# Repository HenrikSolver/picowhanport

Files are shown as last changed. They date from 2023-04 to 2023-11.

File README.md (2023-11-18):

# Ett enkelt sätt att koppla din nya elmätare till en MQTT broker

## Hårdvara
Koppla ihop en 6 pinnars RJ-12 kontakt med picon enligt följande.

| RJ-12 |RJ- 12| RPI |
|---|---|-----|
| 1 (Vcc) | 2 (dataReq) | 39 (VSYS) |
| 5 (data out) | | 7 (UART1 Rx)
| 6 (GND) | | 38 (GND)|

Sätt ett pull upp motstånd på omkring 3 Kohm mellan 7 (UART1 Rx) 36 (3,3V) på pico. Allt enligt nedanstående schema (bidrag från @speedbird620)
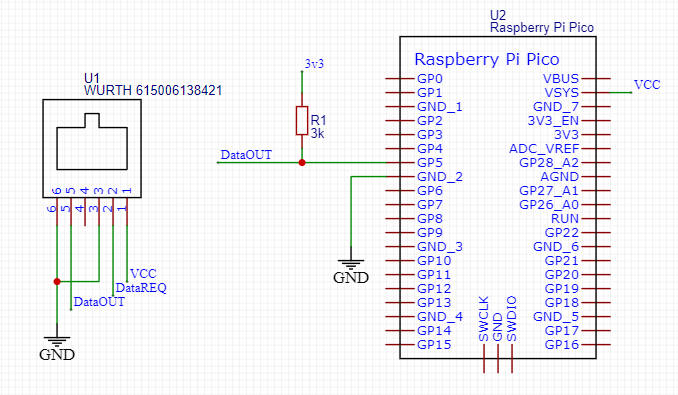
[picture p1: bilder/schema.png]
bild2


## Mjukvara
Installera micropython och mpremote
* https://micropython.org/download/rp2-pico-w/
* https://docs.micropython.org/en/latest/reference/mpremote.html

Modifiera `config.py`så innehållet passar ditt nätverk.
kopiera `config.py` till picon med `mpremote.py cp config.py :config.py`

Installera paketet umqtt.simple med följande 
```python
import mip
import network
import config

wlan = network.WLAN(network.STA_IF)
wlan.active(True)
wlan.connect(config.SSID, config.PSK)

mip.install("umqtt.simple")
```

kopiera `boot.py` och `main.py` till picon med mpremote

koppla in picon till din elmätares HAN port med en rak (altså pin 1 går till pin 1 o.s.v) RJ-12 kabel. LED'en blinkar med omkring 2 Hz medan picon försöker koppla sig till WLAN. När den är uppkopplad lyser den med fast sken men släcks en kort stund för varje gång den får data från elmätaren som skickas till MQTT brokern. Denna släckning skall ske var tionde sekund. Hade det varit en fyr så hade den haft karaktären `Oc 10s`

### komponentlista
Detta är de delar jag använt i bygget, man kan naturligtvis köpa motsvarande någon annanstans. Du behöver också en tång för att klämma modularkontakterna.

* https://www.electrokit.com/produkt/modularkontakt-6-6/
* https://www.electrokit.com/produkt/modularkontakt-6-6-pcb/
* https://www.electrokit.com/produkt/adapterkort-for-rj11-kontakt-2-pack/
* https://www.electrokit.com/produkt/telekabel-6x-0-08mm%c2%b2-platt-vit-m/
* https://www.electrokit.com/produkt/raspberry-pi-pico-w/
* https://www.electrokit.com/produkt/metallfilmsmotstand-0-25w-3-01kohm-1-3k01/

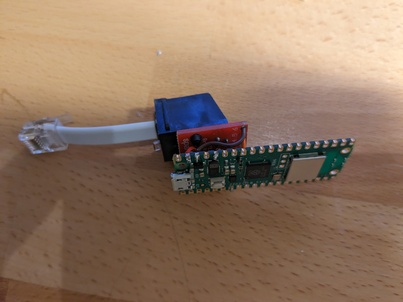
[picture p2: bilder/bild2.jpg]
bild2


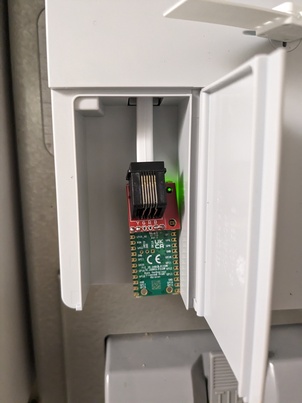
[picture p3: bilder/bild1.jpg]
bild1


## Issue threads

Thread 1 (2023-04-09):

Potential further development: Split Topic into JSON

lillknurra, 2023-04-09:
Hi,
I'm able to get the data into Home Assistant, but it's not easy to make use of the data.

Would it be possible to parse the data into several topics in JSON format?
From this:
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
To something like this:
{ "MeterID":"LGF5E360","1.0.0":"230408233550","1.8.0":"00029737.127","CRC16","0191" }

Or even splitting it further into separate topics...

Thanks,
Petter

JL-EU, 2023-06-04:
Hi,
I'm also trying to get this going, haven't managed to read data from the meter yet.
Did you manage to format the data?
Thanks,
Jacob

lillknurra, 2023-06-04:
Hi,
Yes I managed by reading the lines that are of interest-
I'm using it in home Assistant and created sensors in mqtt.yaml looking like this:
sensor:
  - name: "P1 Energy bought"
    unit_of_measurement: "kWh"
    state_topic: "hanmeter/data"
    device_class: energy
    state_class: total_increasing
    value_template: >-
      {{ value.split("\r\n")[3] | regex_findall_index("\((.+)[*]") | float }}
    icon: mdi:lightning-bolt
    force_update: true
  - name: "P1 Energy sold"
    unit_of_measurement: "kWh"
    state_topic: "hanmeter/data"
    device_class: energy
    state_class: total_increasing
    value_template: >-
      {{ value.split("\r\n")[4] | regex_findall_index("\((.+)[*]") | float }}
    icon: mdi:lightning-bolt
    force_update: true
  - name: "P1 Current Power In"
    unit_of_measurement: "kWh"
    state_topic: "hanmeter/data"
    value_template: >-
      {{ value.split("\r\n")[7] | regex_findall_index("\((.+)[*]") | float }}
    icon: mdi:flash
    force_update: true
  - name: "P1 Current Power Out"
    unit_of_measurement: "kWh"
    state_topic: "hanmeter/data"
    value_template: >-
      {{value.split("\r\n")[8] | regex_findall_index("\((.+)[*]") | float }}
    icon: mdi:flash
    force_update: true

HenrikSolver, 2023-11-09:
I was thinking of this, but then the CRC should be verified before converting the package to JSON, and I thought it was simpler to send the package to "the other side" where verifying the checksum is done by a Go program that stores the data in a influx db.

vilhelmericson, 2023-12-31:
Henrik's nice repository gave me good help to read out the values from my electricity meter's HAN port ([Kamstrup Omnipower](https://www.kamstrup.com/se-se/ellosningar/smarta-elmatare/meters/omnipower-three-phase-meter) + [Kamstrup HAN-P1](https://www.kamstrup.com/se-se/ellosningar/smarta-elmatare/modules/han-p1)) for Home Assistant using a Raspberry Pi Pico and MQTT. To do that, I needed to implement support for the steps that weren't part of Henrik's use case; verify the telegram based on the CRC checksum, interpret the telegram and pack it as a JSON object and then publish it in the MQTT server. The implementation is in the attached zip file, values for all settings are set in config.py. Attached is also an example of how the JSON objects look.
[picowhanport_ha.zip](https://github.com/HenrikSolver/picowhanport/files/13802371/picowhanport_ha.zip)
[telegram.json](https://github.com/HenrikSolver/picowhanport/files/13802372/telegram.json)

HenrikSolver, 2024-01-01:
Nice, and first thing on the new year :+1: . I will take a look and add it in one way or another.

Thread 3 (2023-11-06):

5v från HAN-port, 3v på Pico?!

speedbird620, 2023-11-06:
Hej @HenrikSolver,

Jag tolkar din skiss som att Data UT (PIN5 på RJ12) går till PIN7 på Pico:n.

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

Då processorn på PI Pico arbetar med 3 volt och HAN-portens utgång är på 5 volt, är detta inte enligt spec. Jag är rädd för att det finns risk finns att Picon pajar i längden.

En annan sak jag funderar på, när jag läser på forum så ska Data UT inverteras för att microprocessorn ska läsa informationen. I din design finns inte det inkluderat. Är detta något du löser i mjukvaran?

/mik

HenrikSolver, 2023-11-09:
Hej mik.
Tack för din fråga.
DataOut från  elmätaren är open collector och matas från 3,3v via 3k motståndet som nämns i instruktionerna, så det borde funka. Inventeringen löses i mjukvaran. Eller egentligen  genom att konfigurera UARTen så den inverterar signalen.
/Henrik

speedbird620, 2023-11-11:
Rgr. Då är jag med. Tack för svar.

Stämmer denna skiss?
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

HenrikSolver, 2023-11-11:
Ser bra ut. Vill du göra en PR på README filen för att lägga till skissen? Om du tycker det krångligt kan jag göra det själv (med en hänvisning till dig förstås) det tar mig inte så många minuter.

speedbird620, 2023-11-11:
Nu är jag inte direkt en fena på GitHub, så jag har ingen aning om hur man gör en PR. Om du vill så får du gärna återanvända skissen jag gjorde. Du behöver inte lämna någon referens.

gurka, 2024-11-14:
Hej,

Tänkte att jag kunde ställa lite frågor relaterat till skissen här istället för att göra en ny issue.

- Visst har det försvunnit i nya skissen att DataREQ ska kopplas mot VCC på RJ12:an?
- På tal om DataREQ: är det OK att koppla ihop denna med VCC direkt eller bör det sitta en resistor mellan? Aidon har skrivit så här i deras manual: `Ingång för databegäran är avsedd att sänka strömmen med 4,0–10,0 mA när den aktiveras`, men jag är inte säker på vad det innebär. Menar dom att det sitter en resistor eller motsvarande innanför HAN-porten?
- Spelar det någon roll att man bara kopplar GND från RJ12 till en GND-pinne på pico:n, som i andra skissen, eller bör man koppla den mot alla GND-pinnar som i första skissen?

HenrikSolver, 2024-11-14:
Halloj Gurka.

1. Det står i och för sig i tabellen att de skall kopplas ihopa, men jag håller med om att det kanske inte är supertydligt.
2. Den mest detaljerade informationen jag kan hitta på interfacet är [denna](https://www.netbeheernederland.nl/sites/default/files/2024-02/dsmr_5.0.2_p1_companion_standard.pdf). I schemat på sidan 7 sitter det ett motstånd mellan optokopplaren och data_request. Det verkar vettigt att det gör det för att skydda mätaren.
3. Det verkar inte spela någon roll, jag har bara kopplat in GND till en pinne, och det har fungerat fint.

Henrik

gurka, 2024-11-14:
Aha, så DataREQ och dess optokopplare blir då, mer eller mindre, som som en enkel LED seriekopplad med en resistor. 4mA-10mA är den ström som krävs för att driva denna optokopplare / LED.

Ska bli spännande att se om jag kan få till en fungerande läsare. Just nu verkar dock Pico W vara slutsåld hos de flesta återförsäljare, så vi får se när det blir.

Tack för svar!

gurka, 2024-11-19:
Jag har nog inte helt förstått hur optokopplaren och open collector fungerar.

Det sitter en LED och en transistor i optokopplaren. När LED:en lyser så blir DATA och DATA_GND sammankopplade via transistorn och man kan läsa ut 0V (low) på DATA? När LED:en inte lyser så bryts kopplingen mellan DATA och DATA_GND, och man kan istället läsa ut 3,3V (high) på DATA, som kommer via resistorn och 3v3?

Är det denna "invertering" (LED på => low på GP5, LED av => high på GP5) som gör att man sen måste invertera tillbaka i mjukvaran / UARTen?

Hur pass stämmer denna beskrivning?

Egentligen undrar jag hur man kom fram till just 3k Ohm och om t.ex. 2k Ohm eller 4k Ohm skulle fungera lika bra, då det är såna jag har hemma :)

HenrikSolver, 2024-11-24:
Halloj gurka.

Det verkar som du förstått hur open collector funkar :-). Valet av motstånd är inte mer vetenskapligt än jag hade sådana i lådan och det funkade. Det nederländska dokumentet säger "From an OSM perspective, the maximum current flowing towards the “Data” line must not exceed 5 mA.". Så det funkar säkert med både 2k och 4k motstånd

gurka, 2024-12-05:
Nu har jag testat mjukvaran och den fungerar perfekt. Det enda jag hade problem med i början var att det var för långt mellan pico:n/elmätaren och access-punkten vilket gjorde att pico:n hade svårt att ansluta till wifi. Till slut lyckades den ansluta och jag kunde se att mqtt-brokern tog emot meddelanden, men direkt jag stängde dörren till elskåpet så tappade den anslutningen.

Jag har löst det temporärt nu genom att en extra AP närmare elskåpet, men en sak jag noterade när pico:n hade problem att ansluta var att den aldrig riktigt lyckades åter-ansluta av sig själv. Jag var tvungen att koppla ur den ur elmätaren och starta om den på så sätt för att den skulle kunna ansluta igen. Jag funderar på om det har med `machine.reset` vs. `machine.soft_reset` att göra?

Som koden ser ut nu så gör man ju en hard reset om wifi-anslutningen skulle misslyckas. Lyckas wifi-anslutningen men kommunikation mot mqtt misslyckas så gör man istället en soft reset, och detta kanske är OK om mqtt misslyckas på grund av att t.ex. brokern är offline. Men om mqtt misslyckas på grund av att den har tappat wifi så kanske man borde göra en hard reset istället?

Med andra ord, man kanske alltid ska göra en hard reset vid fel, för att säkerställa att allting sätts upp korrekt igen?

Closed 2023-11-18.

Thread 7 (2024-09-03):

Aidon 6534

Zuru1, 2024-09-03:
Hi!

Has anyone used this with an Aidon 6534 meter?
I have followed the build instructions in constructing the reader but not getting any data at all.
Using a multimeter does show that everything is connected per design.

Thank you!

gurka, 2024-11-14:
Not sure if this is applicable to you, but we have an Aidon 6534 where it says "RF500" at the port instead of "RJ12" like on this image:  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

I contacted the power company (Skellefteå Kraft) to ask about this and they said that this device supports both the DLMS/COSEM EFS-profile as well as the ASCII-based EFS2-profile. If you enable the port via Skellefteå Kraft's Mina Sidor the former one (DLMS/COSEM) will be enabled. To enable the ASCII EFS2-profile you need to contact them as they have do it manually.

So, you might want to contact your power company and see whether or not it's using the EFS2-profile, and if it's possible to switch to it if it's not.

I haven't tested it yet as I'm waiting for all hardware to arrive.

gurka, 2024-12-05:
> I haven't tested it yet as I'm waiting for all hardware to arrive.

I have now tested this software against an Aidon 6534 and it works great. As I wrote in my previous comment, you might want to double check with your power company whether they enabled the DLMS/COSEM EFS-profile or the ASCII-based EFS2-profile.

Zuru1, 2024-12-08:
Sorry for the late reply, I did finally get it to work.
Thank you for all the help.

Closed 2024-09-03.

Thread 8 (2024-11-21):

TypeError: 'NoneType'

speedbird620, 2024-11-21:
I finally got the connection to my MQTT to work and I had to add a MQTT-user and a password (see blue marking).

While trouble shooting I added the two lines in yellow in order to make thing easier.

The next hurdle I cant get my head around is a "NoneType" error message. Since the Pico isn´t connected to any HAN-meter I don´t understand the issue since there will not be any characters on the UART ... or what am I missing?

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

vilhelmericson, 2024-11-22:
I think you have to connect your Pico to a HAN port/serial port to use uart.readline() successfully using your code, otherwise there will be a timeout, see [this query and its answers](https://www.techrepublic.com/forums/discussions/typeerror-nonetype-object-is-not-subscriptable/). Based on that I use this code in my Pico to read a line from the HAN port:
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

Tip: During development or testing, i.e. when the Pico isn't connected to a HAN port, you can fake a port using a text file instead as shown in the code below:
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
When using the faked port, i.e. when using the uart file object, you can use the same code to read lines from the file as used when  reading lines from the HAN port. I use this text file to fake the port, [test_data.txt](https://github.com/user-attachments/files/17853551/test_data.txt)

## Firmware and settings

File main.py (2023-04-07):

import network
import time
import gc
import machine
import config
from machine import UART
from machine import Pin
from umqtt.simple import MQTTClient


uart = UART(1, baudrate=115200, invert=UART.INV_RX, rx=Pin(5), timeout=11000)

led = machine.Pin("LED", machine.Pin.OUT)
led.on()

network.hostname('HANmeter')
wlan = network.WLAN(network.STA_IF)
wlan.active(True)
wlan.connect(config.SSID, config.PSK)
led.off()

waitcount = 0
while wlan.status() != 3:
   waitcount+=1
   time.sleep(0.5)
   led.toggle()
   if waitcount > 120:
      led.off()
      machine.reset()

#led on when connected to wlan
led.on()
print("WIFI CONNECTED")
mqc = MQTTClient("HANMeter", config.MQTTHost, 1883)
try:
   mqc.connect()
except:
   machine.soft_reset()
print("MQTT CONNECTED")
workbuffert = bytearray(1024)
mv = memoryview(workbuffert)

while True:
   mvpos=0
   s = uart.readline()
   while s[0] != ord('/'):
      s = uart.readline()
   #print("NEW HAN PACKAGE")

   mv[mvpos : mvpos+len(s)] = s
   mvpos += len(s)
   led.off()
   while s[0]!= ord('!'):
      s = uart.readline()
      mv[mvpos : mvpos+len(s)] = s
      mvpos += len(s)
   try:
      mqc.publish(config.MQTTTopic,workbuffert[0:mvpos])
   except:
      machine.soft_reset()

   gc.collect()
   led.on()

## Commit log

2023-04-07 soft_reset if connection to mqtt fails
    This prevent the program to stop if the MQTT broker is rebooted
    [main.py]
2023-11-18 Add schematics
